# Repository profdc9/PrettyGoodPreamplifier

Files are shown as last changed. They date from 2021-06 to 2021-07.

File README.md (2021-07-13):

# Pretty Good Preamplifier

This is a stereo preamplifier circuit designed by Daniel Marks, including schematic and gerbers.

It has the following features:

1.  Four selectable audio sources, selected by relays.
2.  One of the audio sources is a balanced XLR input, the other three are unbalanced RCA inputs.
3.  Bass and treble tone control (Baxandall tone control).
4.  Balance control.
5.  A subwoofer output with adjustable gain and corner frequency between 20 and 100 Hz.
6.  Unbalanced and balanced (XLR) outputs for stereo and subwoofer channels.
7.  Supports a toggle power switch or a volume knob power switch.
8.  Can be turned on using remote trigger.
0.  Can send a remote trigger signal when turned on (for example to an amplifier).

It is a two-sided PCB that can be manufactured cheaply by, for example, JLCPCB or PCBWay.  The LM4562 is preferentially used for the op-amps, but NE5532 works fine too.  The XLR input uses a THAT1206 or INA137 integrated circuit.  The XLR output uses a THAT1646 or DRV134 integrated circuit.

Here is a picture of the PCB

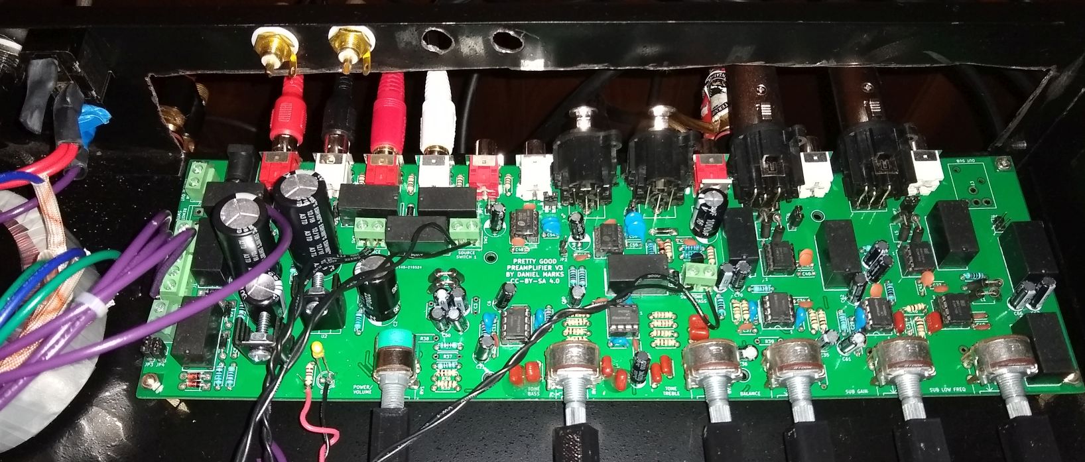
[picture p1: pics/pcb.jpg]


Here is a picture of the full preamplifier with the potentiometer extenders in the CAD directory:

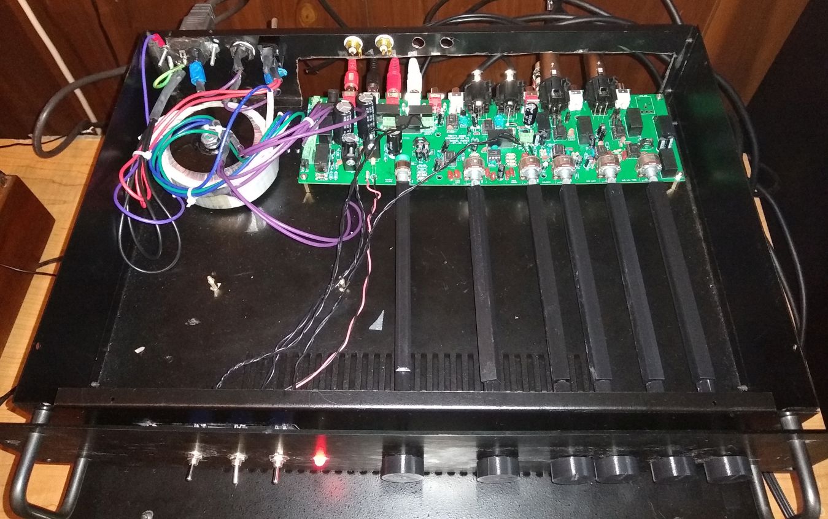
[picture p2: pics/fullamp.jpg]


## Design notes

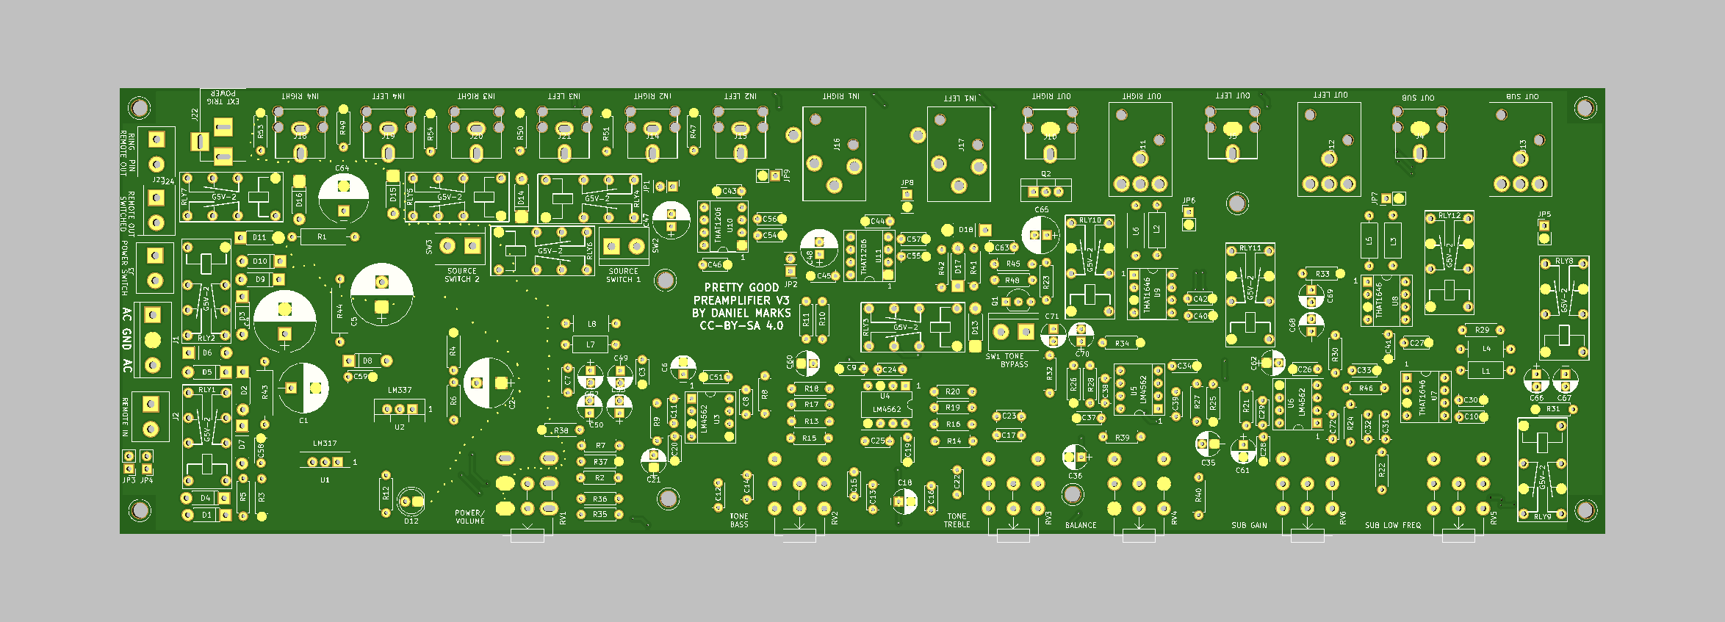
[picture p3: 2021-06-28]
Preamp.png

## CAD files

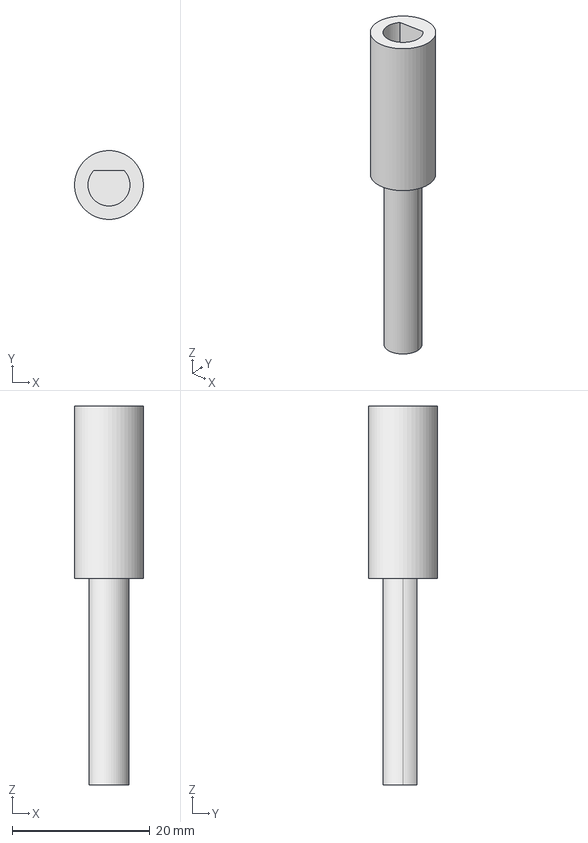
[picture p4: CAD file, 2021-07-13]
CAD/shaft-extender.FCStd
9.99 x 10.00 x 55.0 mm

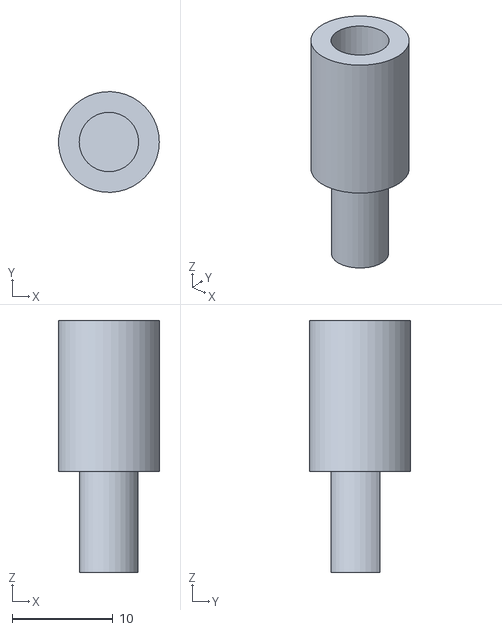
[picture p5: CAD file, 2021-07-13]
CAD/knobextender.stl
9.99 x 9.99 x 25.0

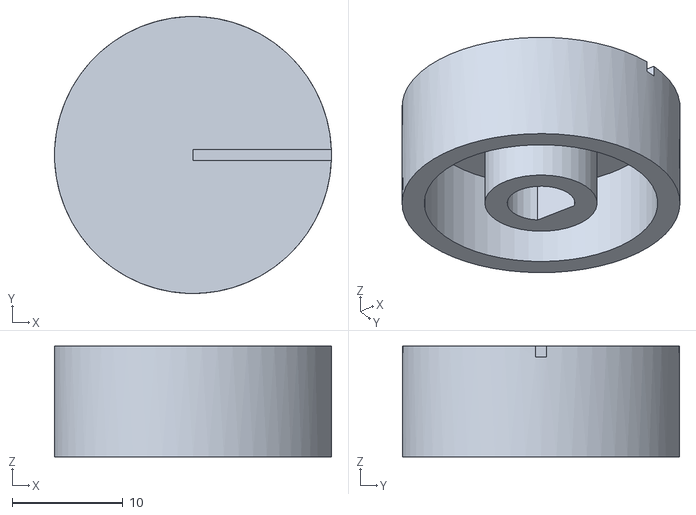
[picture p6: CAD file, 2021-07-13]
CAD/potentiometer-knob.stl
25.0 x 25.0 x 10.0

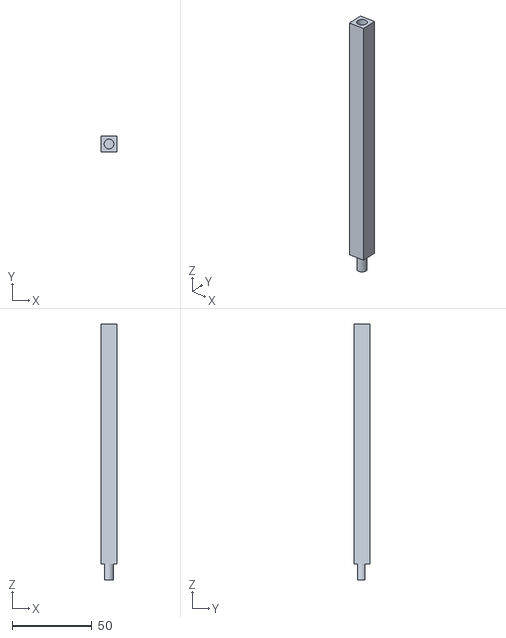
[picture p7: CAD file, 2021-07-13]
CAD/pot-extend-150mm.stl
10.0 x 10.0 x 160.0

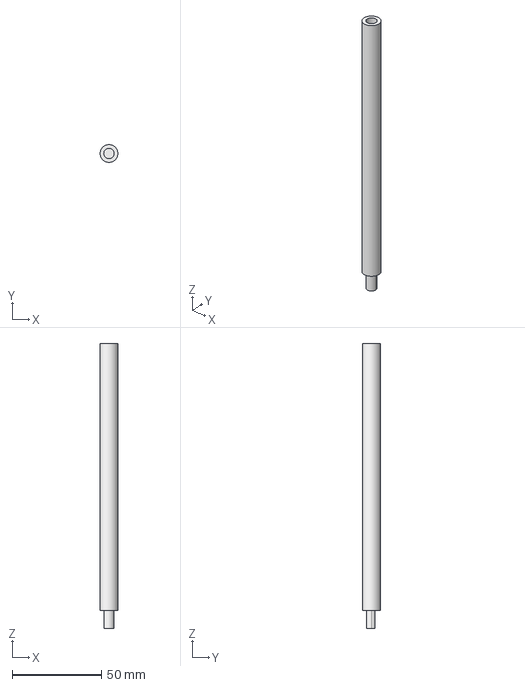
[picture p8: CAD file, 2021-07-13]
CAD/potentiometer-extender.FCStd
9.99 x 10.00 x 160.0 mm

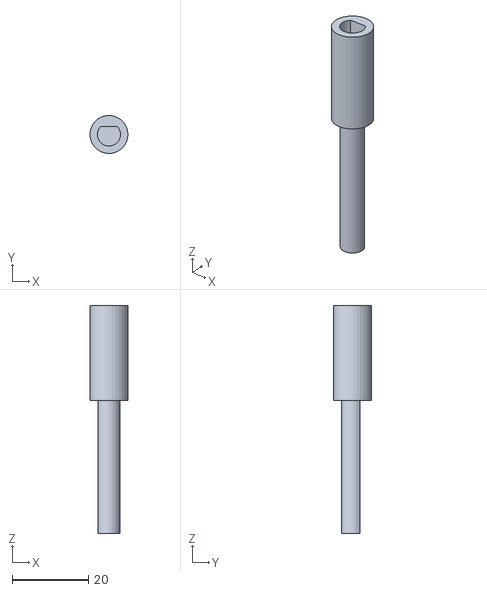
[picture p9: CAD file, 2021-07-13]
CAD/shaft-extender-35mm.stl
9.97 x 9.99 x 60.0

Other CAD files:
CAD/potentiometer-extender-square.FCStd
CAD/pot-extend-10mm-test.stl
CAD/custom-knob.FCStd
CAD/shaft-extender.stl

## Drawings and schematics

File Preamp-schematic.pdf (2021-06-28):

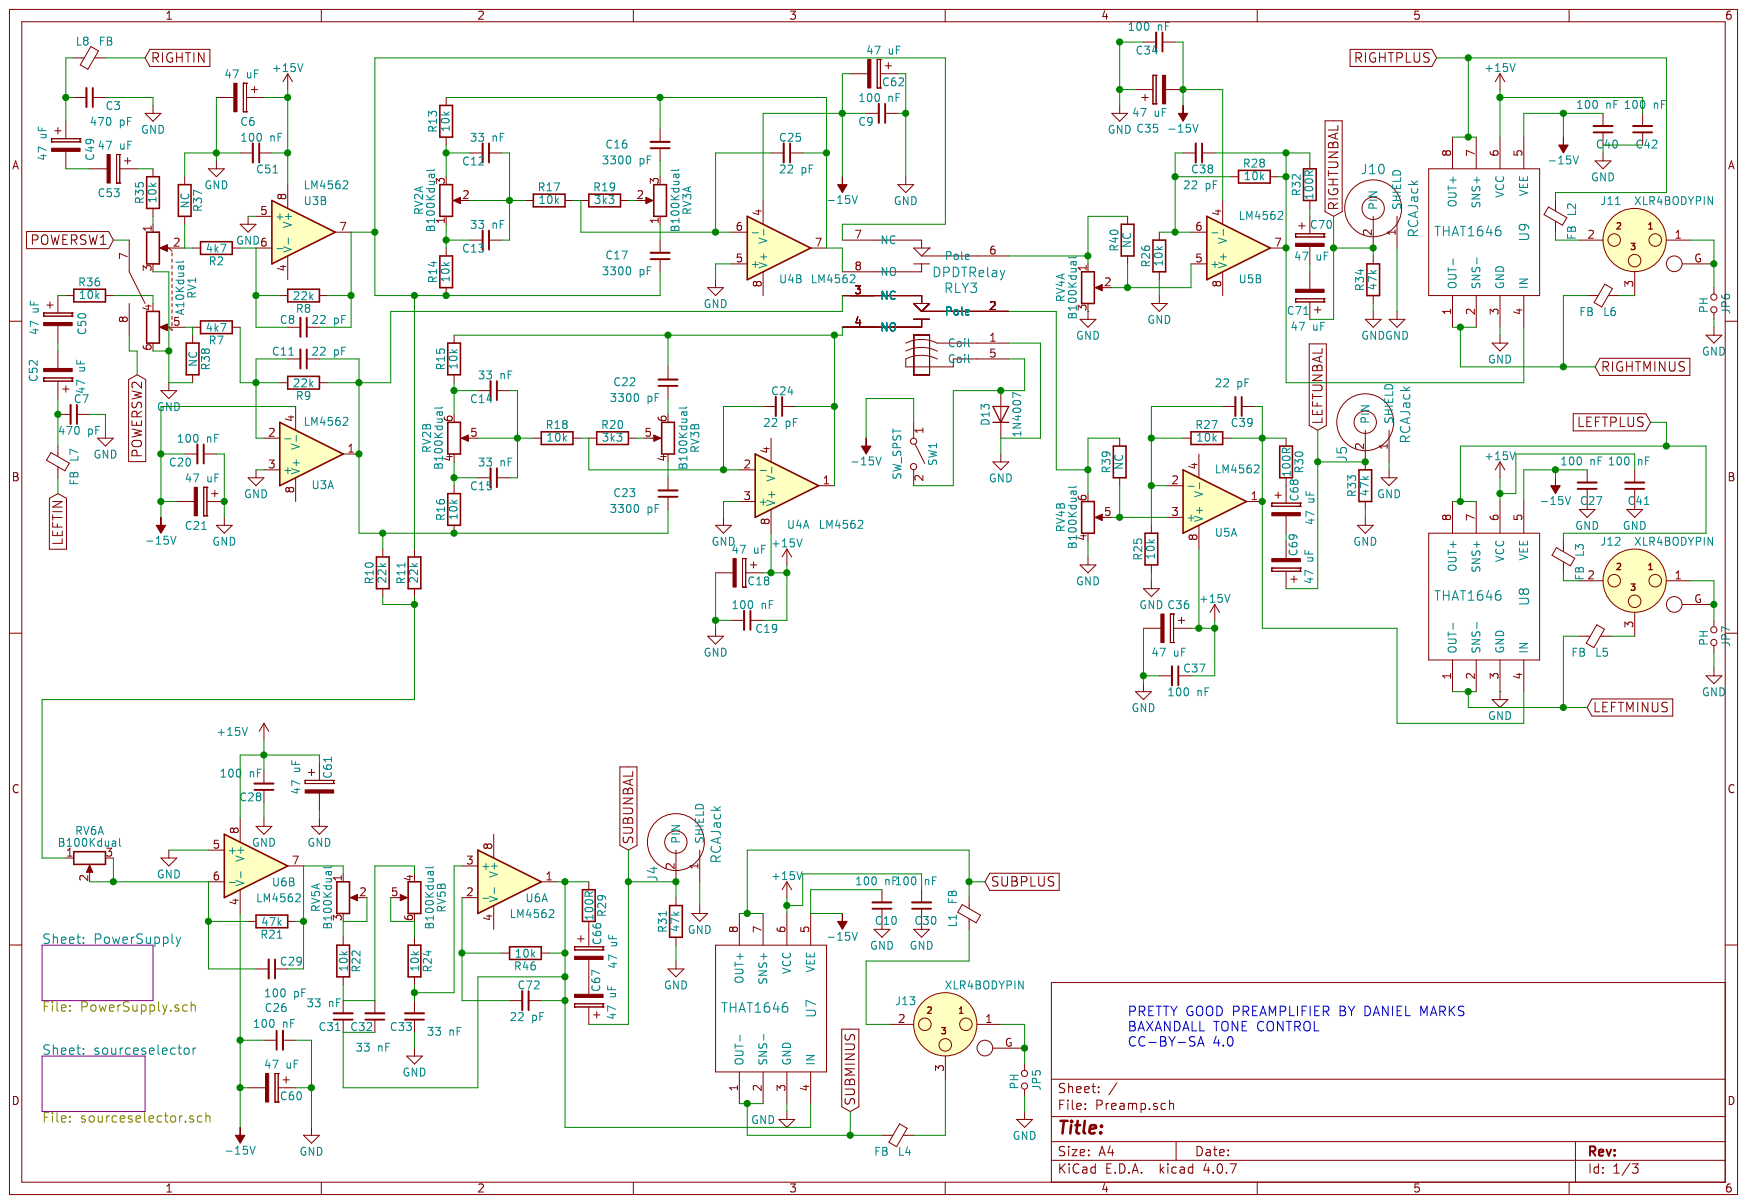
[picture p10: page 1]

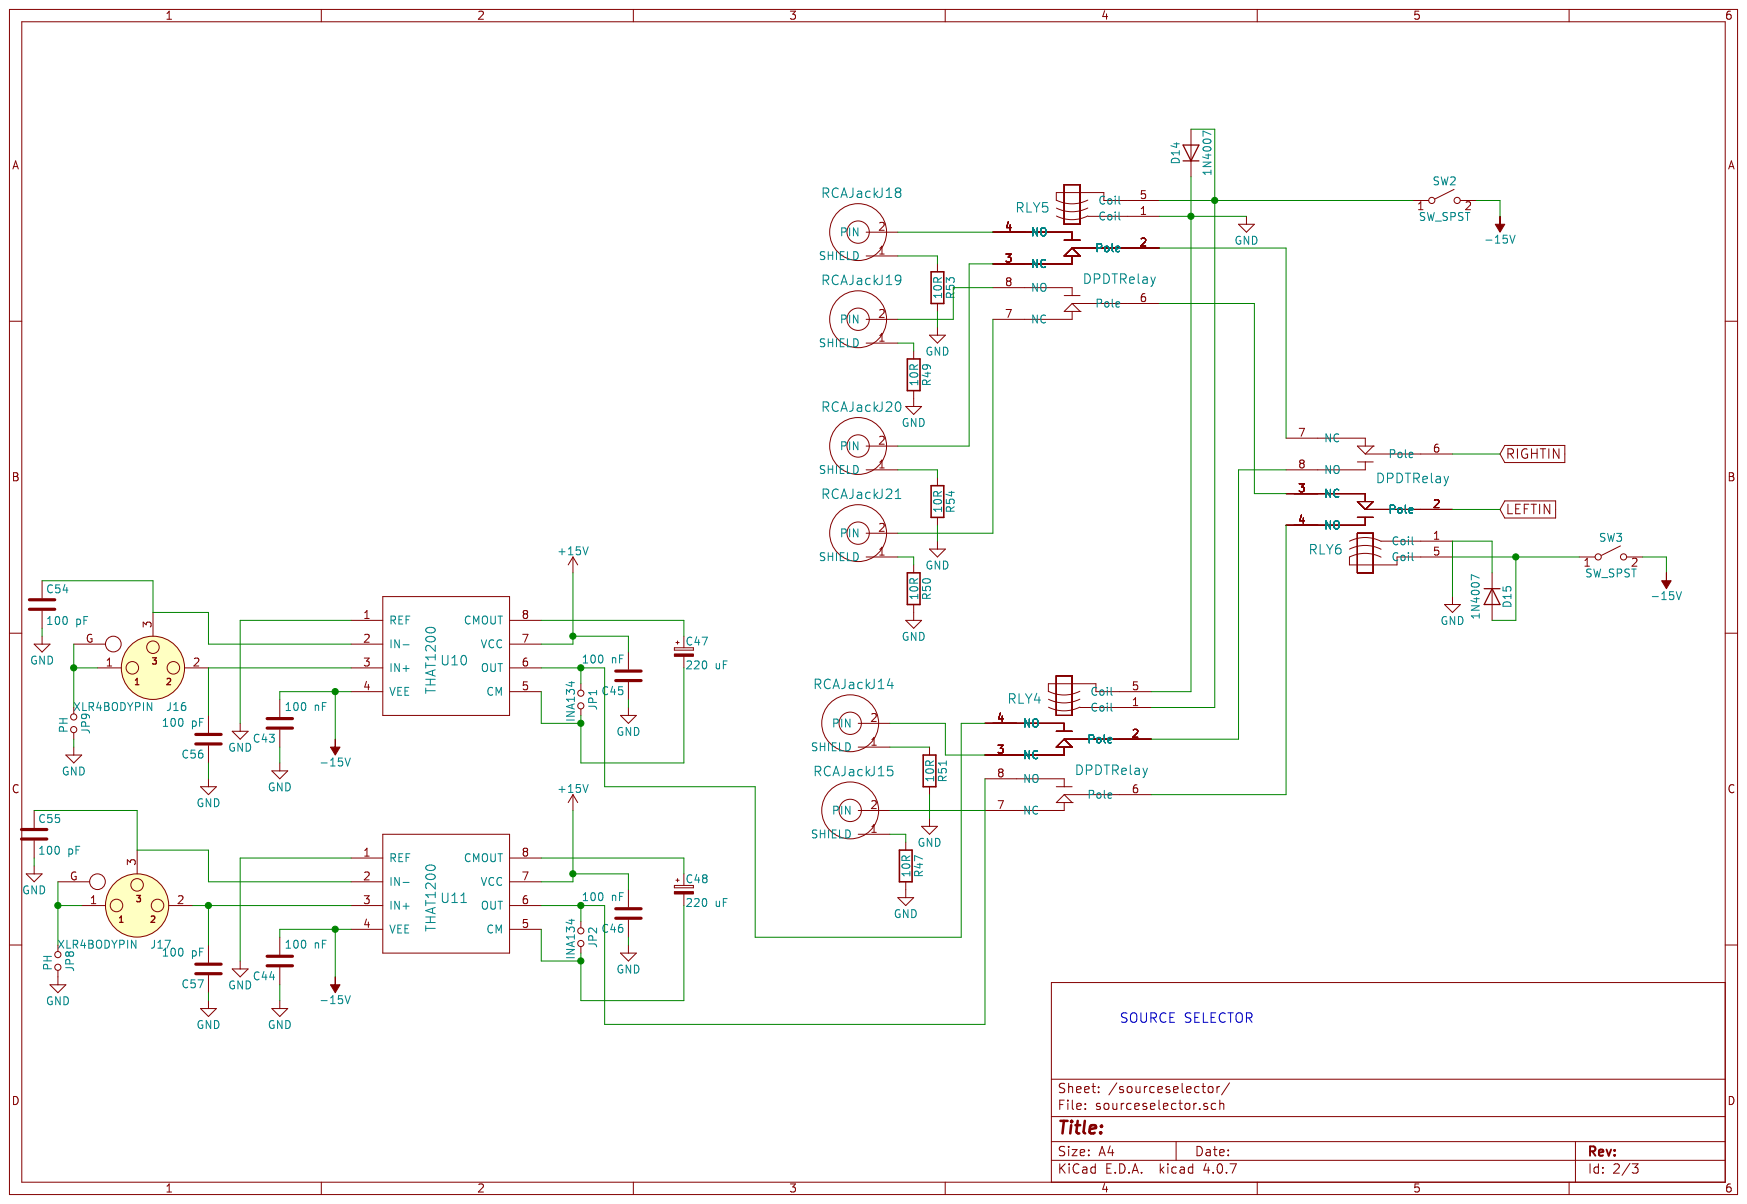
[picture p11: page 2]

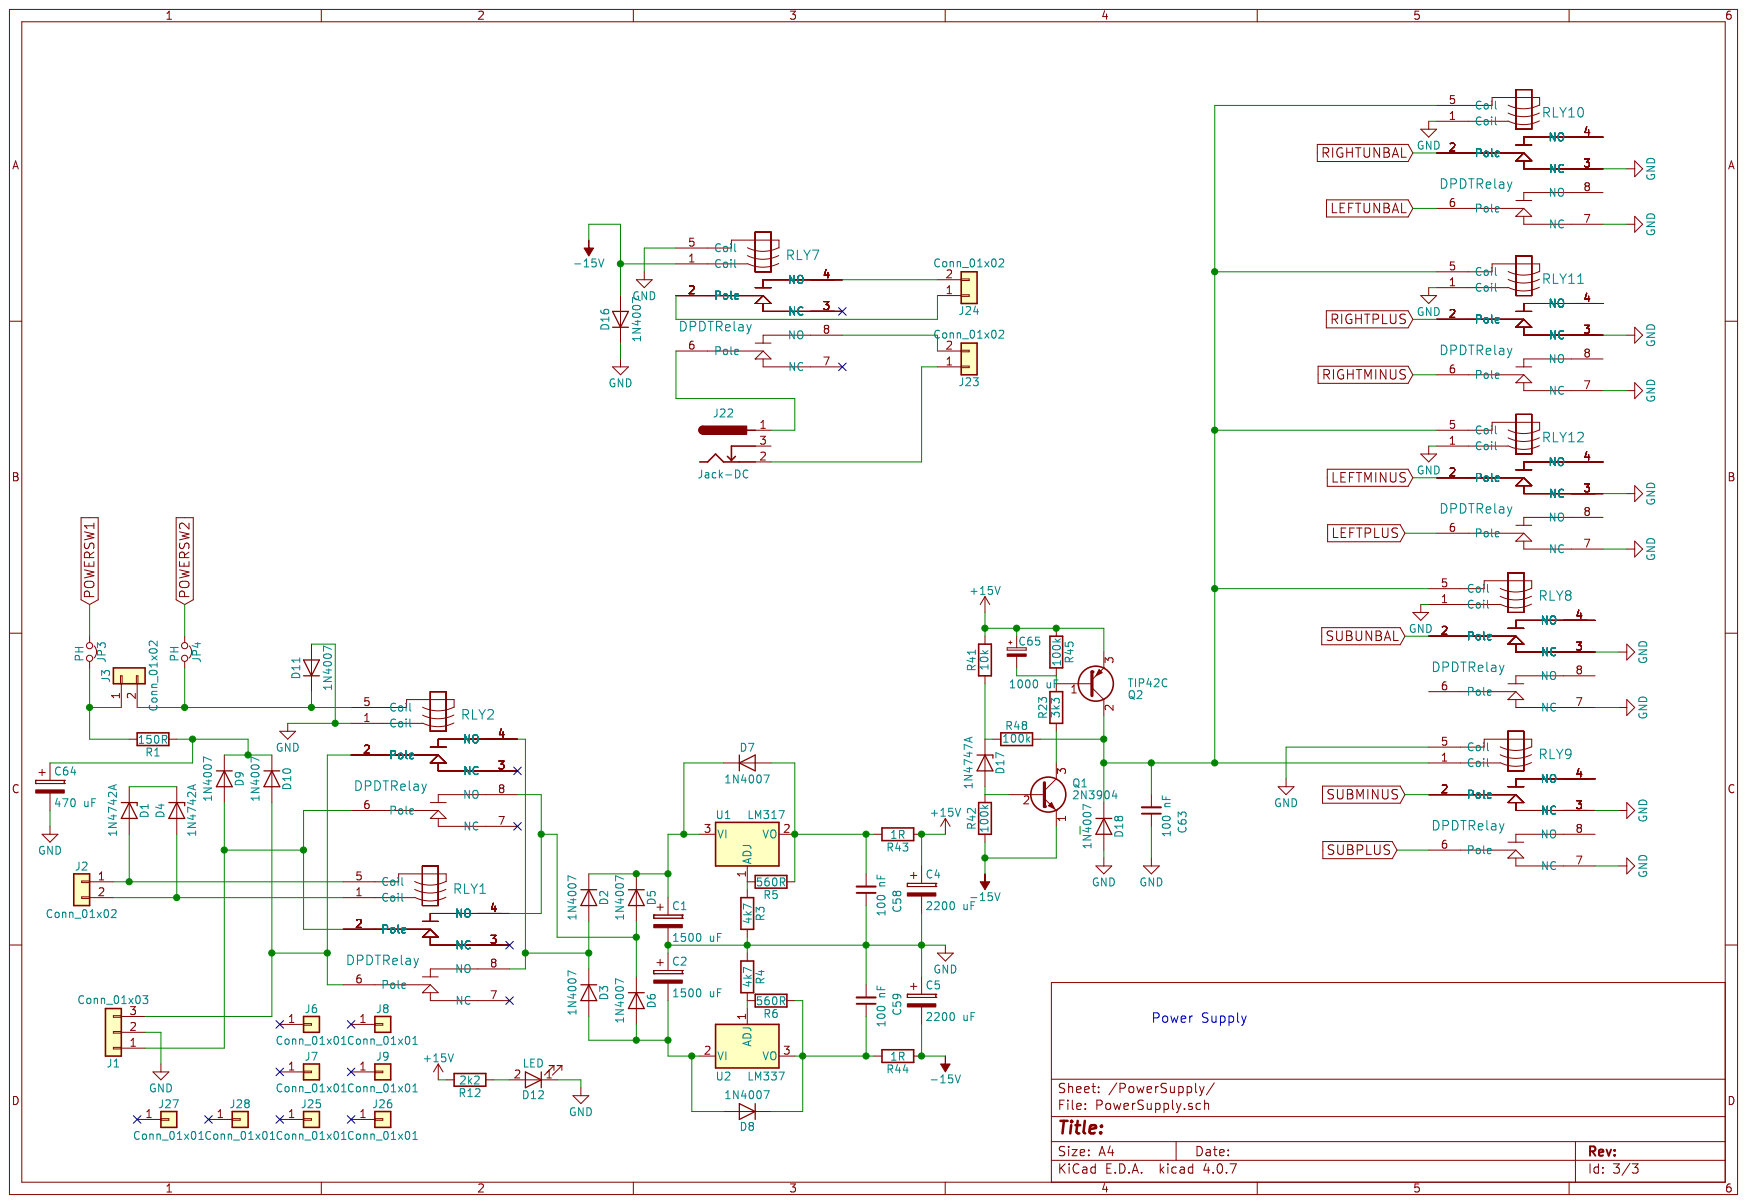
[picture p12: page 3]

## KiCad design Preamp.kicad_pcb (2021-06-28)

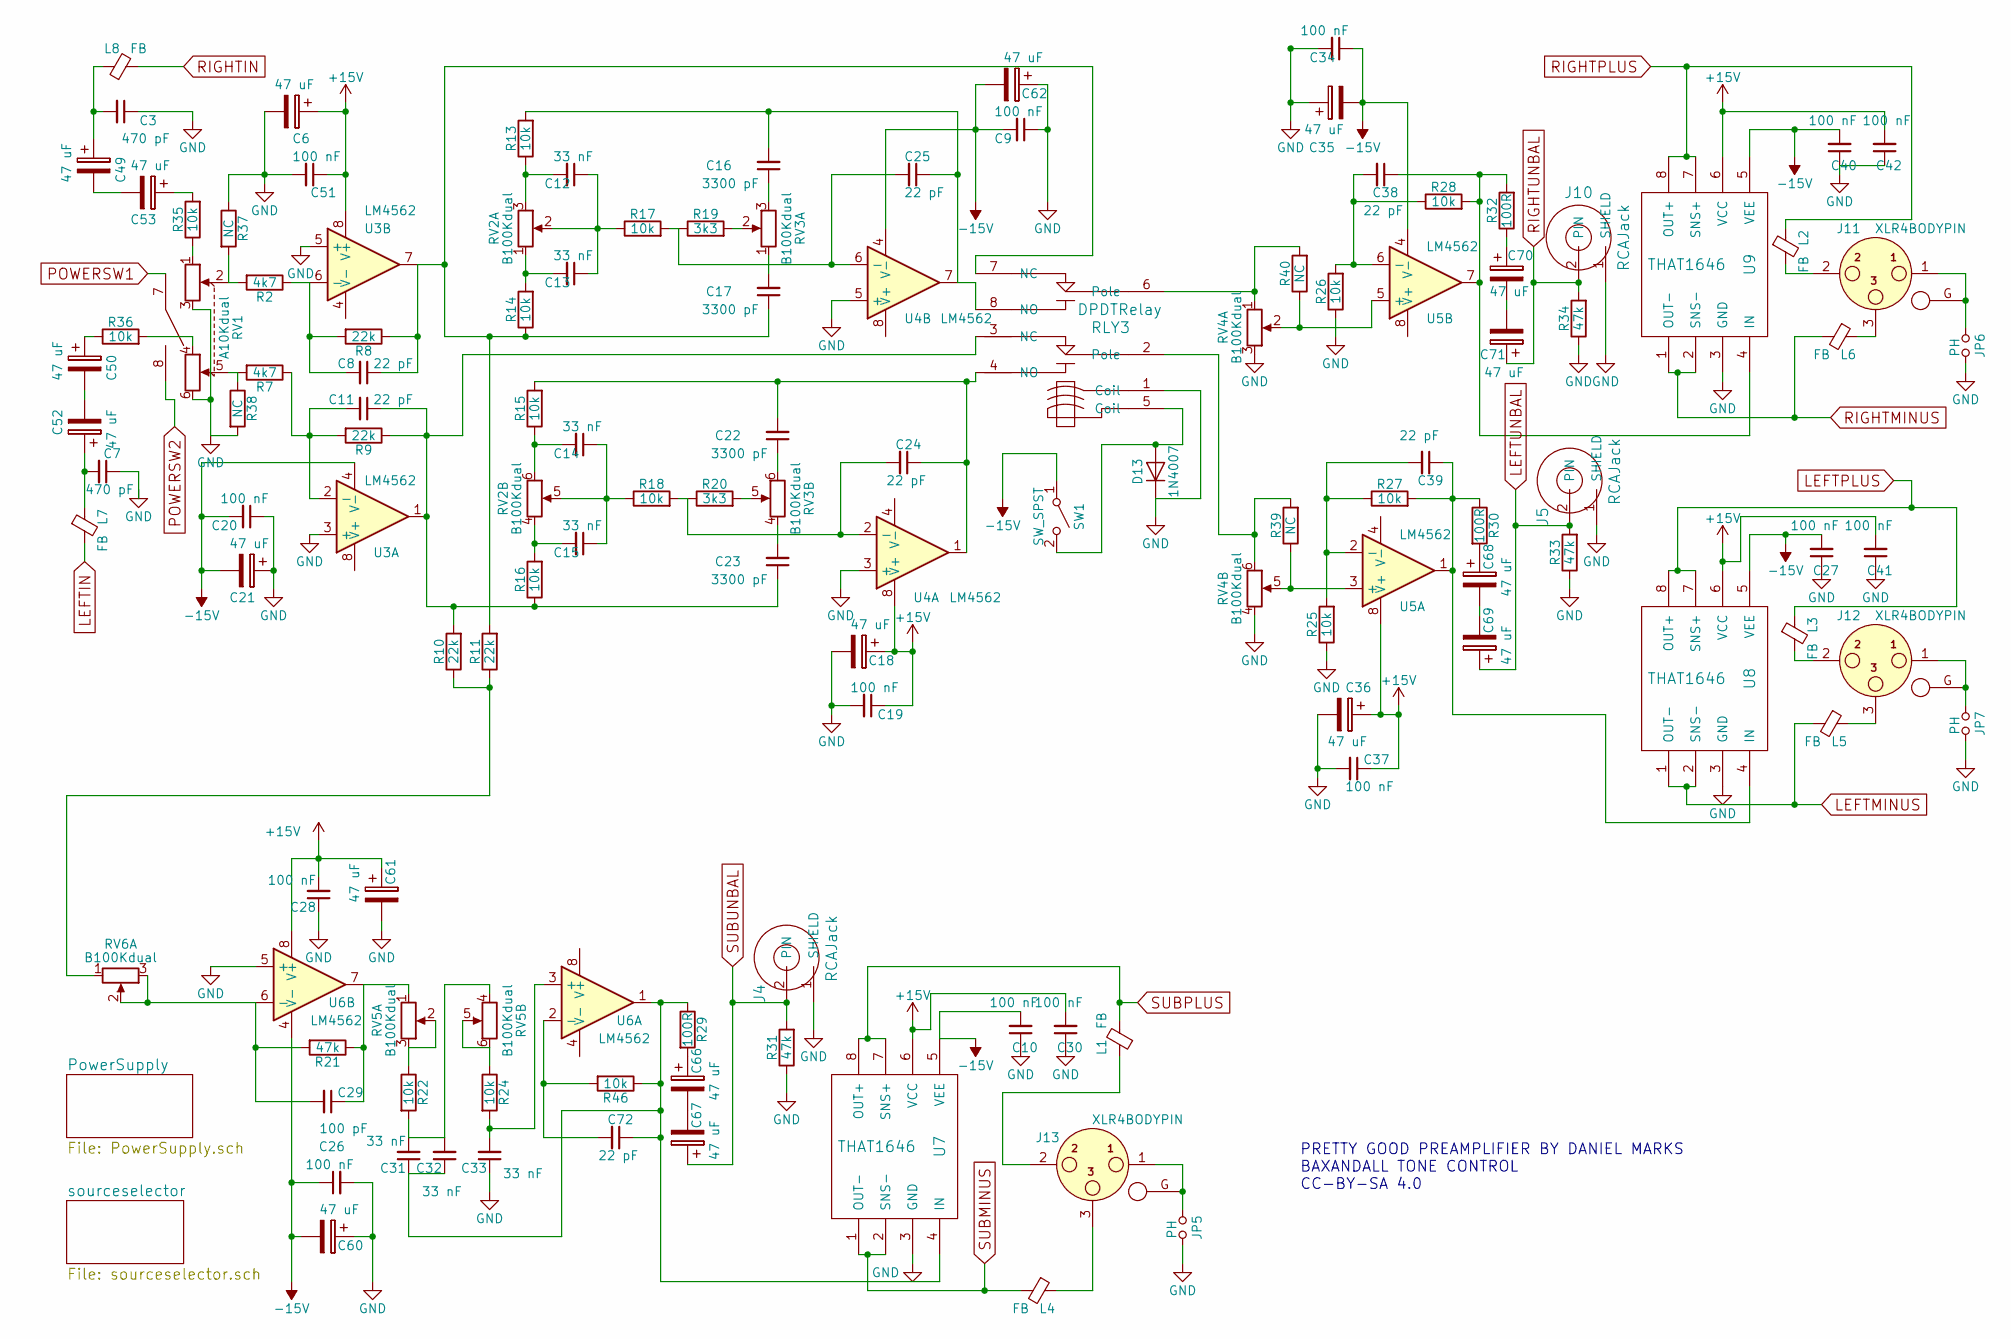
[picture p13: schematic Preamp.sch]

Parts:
C3, C7: 470 pF; C_Disc_D5.0mm_W2.5mm_P5.00mm
C6, C18, C21, C35, C36, C49, C50, C52, C53, C60, C61, C62, C66, C67, C68, C69, C70, C71: 47 uF; CP_Radial_D5.0mm_P2.50mm
C8, C11, C24, C25, C38, C39, C72: 22 pF; C_Disc_D5.0mm_W2.5mm_P5.00mm
C9, C10, C19, C20, C26, C27, C28, C30, C34, C37, C40, C41, C42, C51: 100 nF; C_Disc_D5.0mm_W2.5mm_P5.00mm
C12, C13, C14, C15, C31, C32, C33: 33 nF; C_Disc_D5.0mm_W2.5mm_P5.00mm
C16, C17, C22, C23: 3300 pF; C_Disc_D5.0mm_W2.5mm_P5.00mm
C29: 100 pF; C_Disc_D5.0mm_W2.5mm_P5.00mm
D13: 1N4007; D_DO-41_SOD81_P7.62mm_Horizontal
J4, J5, J10: RCAJack; RCAConnectorCommon
J11, J12, J13: XLR4BODYPIN; IOXLR3MEH
JP5, JP6, JP7: PH; Pin_Header_Straight_1x02_Pitch2.54mm
L1, L2, L3, L4, L5, L6, L7, L8: FB; L_Axial_L7.0mm_D3.3mm_P10.16mm_Horizontal_Fastron_MICC
R2, R7: 4k7; R_Axial_DIN0207_L6.3mm_D2.5mm_P7.62mm_Horizontal
R8, R9, R10, R11: 22k; R_Axial_DIN0207_L6.3mm_D2.5mm_P7.62mm_Horizontal
R13, R14, R15, R16, R17, R18, R22, R24, R25, R26, R27, R28, R35, R36, R46: 10k; R_Axial_DIN0207_L6.3mm_D2.5mm_P7.62mm_Horizontal
R19, R20: 3k3; R_Axial_DIN0207_L6.3mm_D2.5mm_P7.62mm_Horizontal
R21, R31, R33, R34: 47k; R_Axial_DIN0207_L6.3mm_D2.5mm_P7.62mm_Horizontal
R29, R30, R32: 100R; R_Axial_DIN0207_L6.3mm_D2.5mm_P7.62mm_Horizontal
R37, R38, R39, R40: NC; R_Axial_DIN0207_L6.3mm_D2.5mm_P7.62mm_Horizontal
RLY3: DPDTRelay; G2VRelay
RV1: A10Kdual; Dual_Potentiometer_Switch_Wide_WirePads
RV2, RV3, RV4, RV5, RV6: B100Kdual; Dual_Potentiometer_Switch_WirePads
SW1: SW_SPST; TerminalBlock_bornier-2_P5.08mm
U3, U4, U5, U6: LM4562; DIP-8_W7.62mm_Socket
U7, U8, U9: THAT1646; DIP-8_W7.62mm_Socket

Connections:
+15V: C6.1, C18.1, C19.1, C28.2, C30.2, C36.1, C37.1, C41.2, C42.2, C51.1, C61.1, U3.8 (V+), U4.8 (V+), U5.8 (V+), U6.8 (V+), U7.6 (VCC), U8.6 (VCC), U9.6 (VCC); also elsewhere on the board
-15V: C9.2, C10.2, C20.2, C21.2, C26.1, C27.2, C34.1, C35.2, C40.2, C60.2, C62.2, SW1.1 (A), U3.4 (V-), U4.4 (V-), U5.4 (V-), U6.4 (V-), U7.5 (VEE), U8.5 (VEE), U9.5 (VEE); also elsewhere on the board
LEFTIN: L7.2; also elsewhere on the board
LEFTMINUS: L5.2, U8.1 (OUT-), U8.2 (SNS-); also elsewhere on the board
LEFTPLUS: L3.1, U8.7 (SNS+), U8.8 (OUT+); also elsewhere on the board
LEFTUNBAL: C69.1, J5.2 (PIN), R33.2; also elsewhere on the board
unnamed: C3.2, C49.1, L8.1
unnamed: C8.2, R2.1, R8.2, U3.6 (-)
unnamed: C11.1, C23.1, R9.1, R10.2, R16.1, RLY3.3 (NC), U3.1
unnamed: C11.2, R7.1, R9.2, U3.2 (-)
unnamed: C12.1, C13.1, R17.1, RV2.2 (5)
unnamed: C12.2, R13.1, RV2.3 (6)
unnamed: C13.2, R14.2, RV2.1 (4)
unnamed: C14.1, C15.1, R18.1, RV2.5
unnamed: C14.2, R15.1, RV2.6
unnamed: C15.2, R16.2, RV2.4
unnamed: C16.1, RV3.3 (6)
unnamed: C16.2, C25.1, R13.2, RLY3.8 (NO), U4.7
unnamed: C8.1, C17.1, R8.1, R11.2, R14.1, RLY3.7 (NC), U3.7
unnamed: C17.2, RV3.1 (4)
unnamed: C22.1, RV3.6
unnamed: C22.2, C24.1, R15.2, RLY3.4 (NO), U4.1
unnamed: C23.2, RV3.4
unnamed: C24.2, R18.2, R20.1, U4.2 (-)
unnamed: C25.2, R17.2, R19.1, U4.6 (-)
unnamed: C29.1, R21.1, RV5.1 (4), U6.7
unnamed: C29.2, R21.2, RV6.2 (5), RV6.3 (6), U6.6 (-)
unnamed: C31.1, C32.1, C72.1, R29.1, R46.1, U6.1, U7.4 (IN)
unnamed: C31.2, C32.2, R22.2, RV5.4
unnamed: C33.2, R24.2, U6.3 (+)
unnamed: C38.1, R28.2, R32.2, U5.7, U9.4 (IN)
unnamed: C38.2, R26.2, R28.1, U5.6 (-)
unnamed: C39.1, R27.2, R30.1, U5.1, U8.4 (IN)
unnamed: C39.2, R25.2, R27.1, U5.2 (-)
unnamed: C49.2, C53.2
unnamed: C50.1, R36.1
unnamed: C50.2, C52.2
unnamed: C7.2, C52.1, L7.1
unnamed: C53.1, R35.2
unnamed: C66.1, R29.2
unnamed: C66.2, C67.2
unnamed: C68.1, R30.2
unnamed: C68.2, C69.2
unnamed: C70.1, R32.1
unnamed: C70.2, C71.2
unnamed: C72.2, R46.2, U6.2 (-)
unnamed: D13.2 (A), RLY3.5 (Coil), SW1.2 (B)
unnamed: J11.1, J11.G, JP6.1
unnamed: J11.2, L2.2
unnamed: J11.3, L6.1
unnamed: J12.1, J12.G, JP7.1
unnamed: J12.2, L3.2
unnamed: J12.3, L5.1
unnamed: J13.1, J13.G, JP5.1
unnamed: J13.2, L1.1
unnamed: J13.3, L4.1
unnamed: R2.2, R37.2, RV1.2
unnamed: R10.1, R11.1, RV6.1 (4)
unnamed: R19.2, RV3.2 (5)
unnamed: R20.2, RV3.5
unnamed: R22.1, RV5.2 (5), RV5.3 (6)
unnamed: R24.1, RV5.5, RV5.6
unnamed: R35.1, RV1.1
unnamed: R36.2, RV1.4
unnamed: R7.2, R38.1, RV1.5
unnamed: R39.1, RV4.5, U5.3 (+)
unnamed: R39.2, RLY3.2 (Pole), RV4.6
unnamed: R40.1, RV4.2 (5), U5.5 (+)
unnamed: R40.2, RLY3.6 (Pole), RV4.1 (4)
POWERSW1: RV1.7 (SW1); also elsewhere on the board
POWERSW2: RV1.8; also elsewhere on the board
RIGHTIN: L8.2; also elsewhere on the board
RIGHTMINUS: L6.2, U9.1 (OUT-), U9.2 (SNS-); also elsewhere on the board
RIGHTPLUS: L2.1, U9.7 (SNS+), U9.8 (OUT+); also elsewhere on the board
RIGHTUNBAL: C71.1, J10.2 (PIN), R34.2; also elsewhere on the board
SUBMINUS: L4.2, U7.1 (OUT-), U7.2 (SNS-); also elsewhere on the board
SUBPLUS: L1.2, U7.7 (SNS+), U7.8 (OUT+); also elsewhere on the board
SUBUNBAL: C67.1, J4.2 (PIN), R31.2; also elsewhere on the board

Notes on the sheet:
PRETTY GOOD PREAMPLIFIER BY DANIEL MARKS BAXANDALL TONE CONTROL CC-BY-SA 4.0

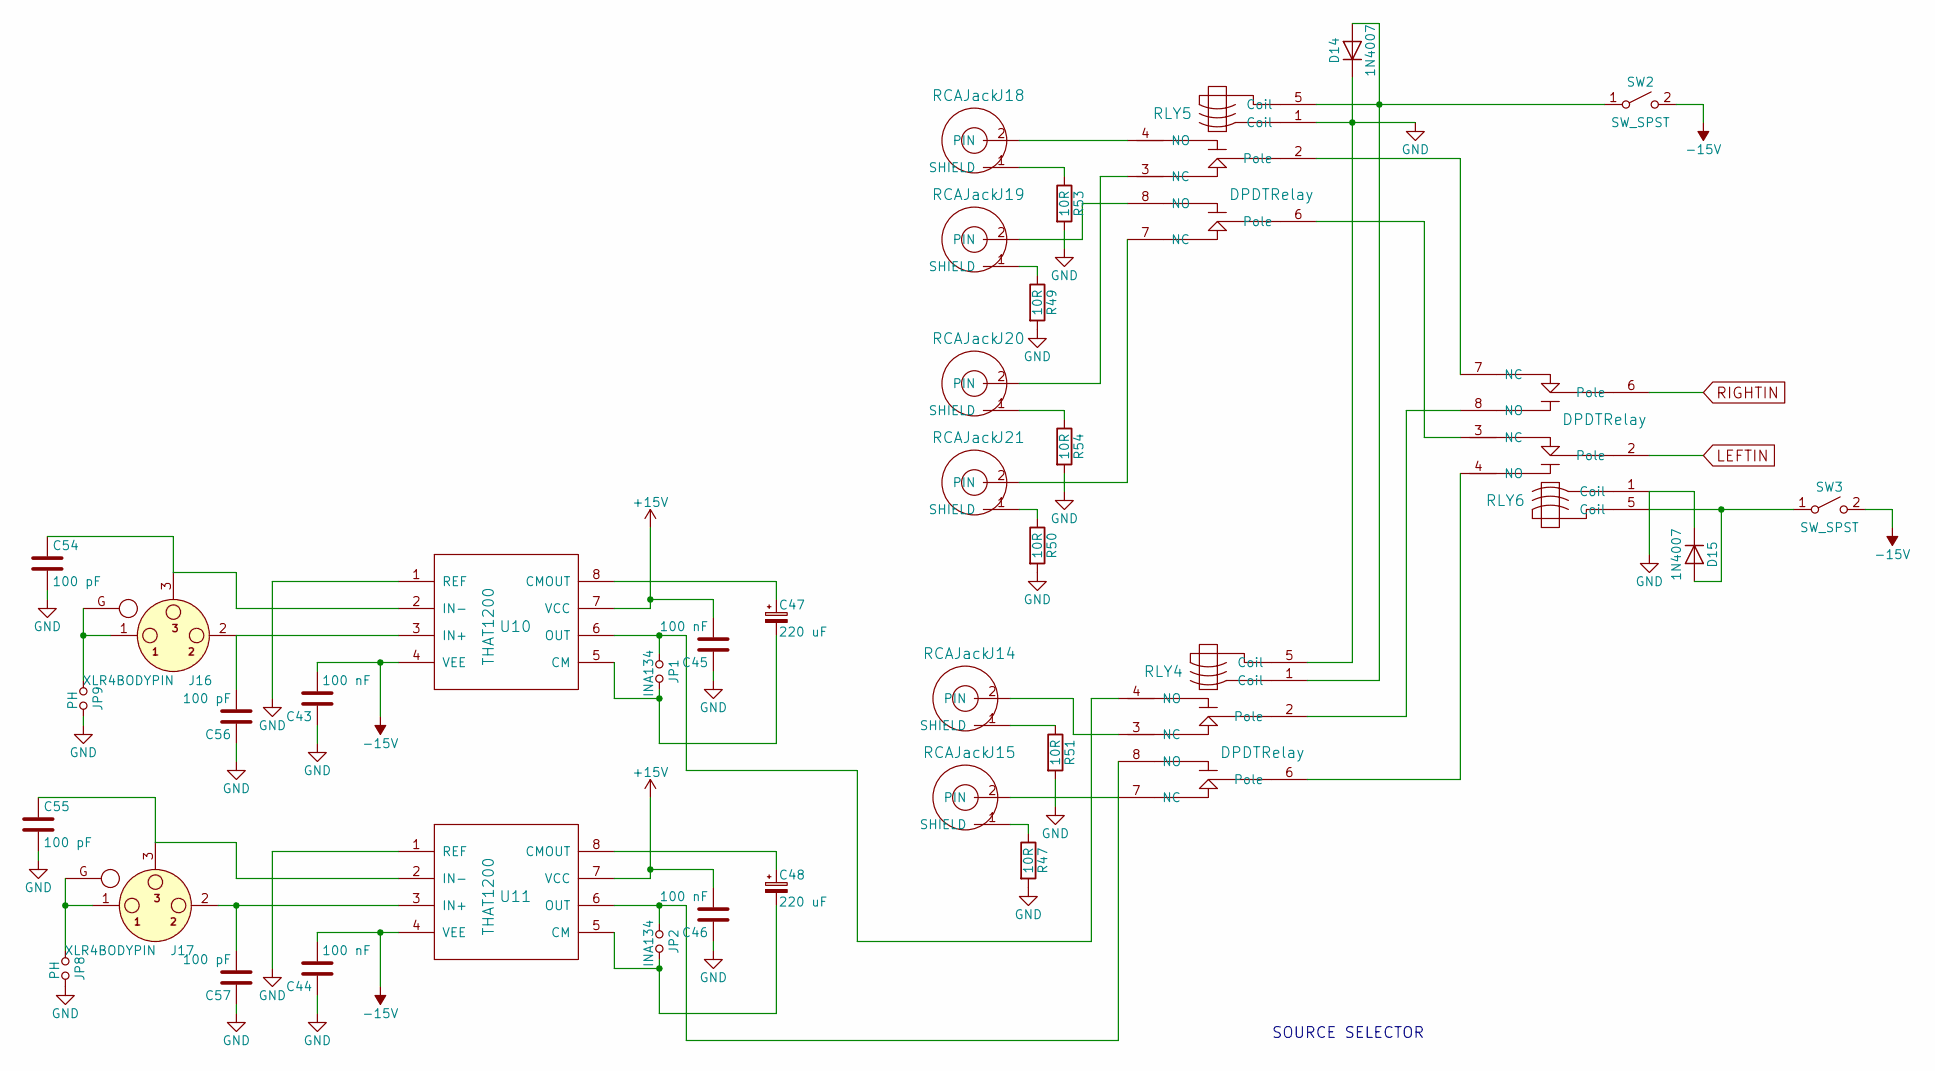
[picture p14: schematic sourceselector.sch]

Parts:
C43, C44, C45, C46: 100 nF; C_Disc_D5.0mm_W2.5mm_P5.00mm
C47, C48: 220 uF; CP_Radial_D7.5mm_P2.50mm
C54, C55, C56, C57: 100 pF; C_Disc_D5.0mm_W2.5mm_P5.00mm
D14, D15: 1N4007; D_DO-41_SOD81_P7.62mm_Horizontal
J14, J15, J18, J19, J20, J21: RCAJack; RCAConnectorCommon
J16, J17: XLR4BODYPIN; IOXLR3FEH
JP1, JP2: INA134; Pin_Header_Straight_1x02_Pitch2.54mm
JP8, JP9: PH; Pin_Header_Straight_1x02_Pitch2.54mm
R47, R49, R50, R51, R53, R54: 10R; R_Axial_DIN0207_L6.3mm_D2.5mm_P7.62mm_Horizontal
RLY4, RLY5, RLY6: DPDTRelay; G2VRelay
SW2, SW3: SW_SPST; TerminalBlock_bornier-2_P5.08mm
U10, U11: THAT1200; DIP-8_W7.62mm_Socket

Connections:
+15V: C45.2, C46.2, U10.7 (VCC), U11.7 (VCC); also elsewhere on the board
-15V: C43.2, C44.2, SW2.2 (B), SW3.2 (B), U10.4 (VEE), U11.4 (VEE); also elsewhere on the board
LEFTIN: RLY6.2 (Pole); also elsewhere on the board
unnamed: C47.1, U10.8 (CMOUT)
unnamed: C47.2, JP1.2, U10.5 (CM)
unnamed: C48.1, U11.8 (CMOUT)
unnamed: C48.2, JP2.2, U11.5 (CM)
unnamed: C54.1, J16.3, U10.2 (IN-)
unnamed: C55.1, J17.3, U11.2 (IN-)
unnamed: C56.2, J16.2, U10.3 (IN+)
unnamed: C57.2, J17.2, U11.3 (IN+)
unnamed: D14.2 (A), RLY4.1 (Coil), RLY5.5 (Coil), SW2.1 (A)
unnamed: D15.2 (A), RLY6.5 (Coil), SW3.1 (A)
unnamed: J14.1 (SHIELD), R51.1
unnamed: J14.2 (PIN), RLY4.3 (NC)
unnamed: J15.1 (SHIELD), R47.1
unnamed: J15.2 (PIN), RLY4.7 (NC)
unnamed: J16.1, J16.G, JP9.1
unnamed: J17.1, J17.G, JP8.1
unnamed: J18.1 (SHIELD), R53.1
unnamed: J18.2 (PIN), RLY5.4 (NO)
unnamed: J19.1 (SHIELD), R49.1
unnamed: J19.2 (PIN), RLY5.8 (NO)
unnamed: J20.1 (SHIELD), R54.1
unnamed: J20.2 (PIN), RLY5.3 (NC)
unnamed: J21.1 (SHIELD), R50.1
unnamed: J21.2 (PIN), RLY5.7 (NC)
unnamed: JP1.1, RLY4.4 (NO), U10.6 (OUT)
unnamed: JP2.1, RLY4.8 (NO), U11.6 (OUT)
unnamed: RLY4.2 (Pole), RLY6.8 (NO)
unnamed: RLY4.6 (Pole), RLY6.4 (NO)
unnamed: RLY5.2 (Pole), RLY6.7 (NC)
unnamed: RLY5.6 (Pole), RLY6.3 (NC)
RIGHTIN: RLY6.6 (Pole); also elsewhere on the board

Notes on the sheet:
SOURCE SELECTOR

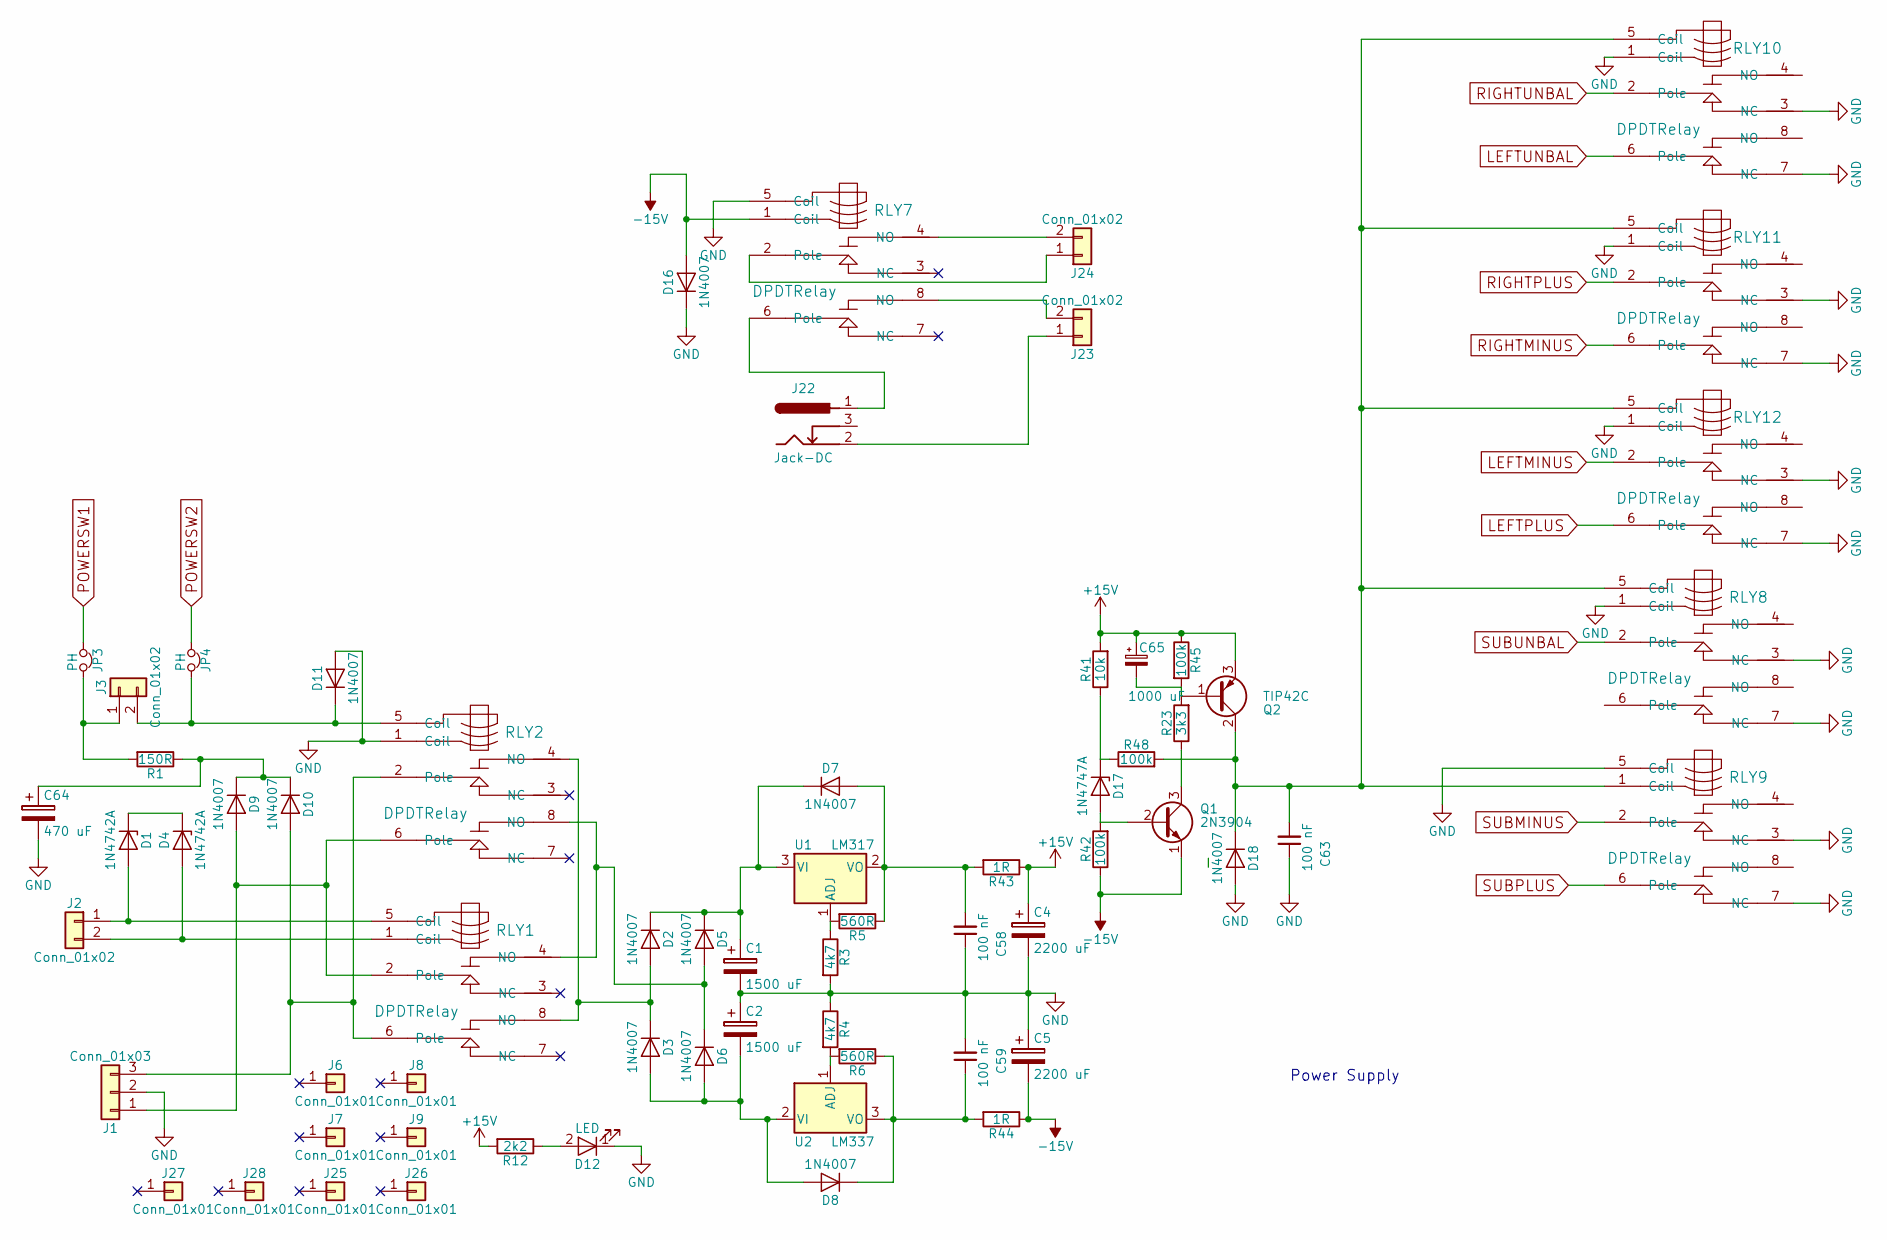
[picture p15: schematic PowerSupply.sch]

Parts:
C1, C2: 1500 uF; CP_Radial_D10.0mm_P5.00mm
C4, C5: 2200 uF; CP_Radial_D12.5mm_P5.00mm
C58, C59, C63: 100 nF; C_Disc_D5.0mm_W2.5mm_P5.00mm
C64: 470 uF; CP_Radial_D10.0mm_P5.00mm
C65: 1000 uF; CP_Radial_D7.5mm_P2.50mm
D1, D4: 1N4742A; D_DO-41_SOD81_P7.62mm_Horizontal
D2, D3, D5, D6, D7, D8, D9, D10, D11, D16, D18: 1N4007; D_DO-41_SOD81_P7.62mm_Horizontal
D12: LED; LED_D5.0mm
D17: 1N4747A; D_DO-41_SOD81_P7.62mm_Horizontal
J1: Conn_01x03; TerminalBlock_bornier-3_P5.08mm
J2, J3, J23, J24: Conn_01x02; TerminalBlock_bornier-2_P5.08mm
J6, J7, J8, J9, J25, J26, J27, J28: Conn_01x01; 1pin
J22: Jack-DC; BARREL_JACK
JP3, JP4: PH; Pin_Header_Straight_1x02_Pitch2.54mm
Q1: 2N3904; TO-92_Inline_Wide
Q2: TIP42C; TO-220-3_Vertical
R1: 150R; R_Axial_DIN0309_L9.0mm_D3.2mm_P12.70mm_Horizontal
R3, R4: 4k7; R_Axial_DIN0207_L6.3mm_D2.5mm_P7.62mm_Horizontal
R5, R6: 560R; R_Axial_DIN0207_L6.3mm_D2.5mm_P7.62mm_Horizontal
R12: 2k2; R_Axial_DIN0207_L6.3mm_D2.5mm_P7.62mm_Horizontal
R23: 3k3; R_Axial_DIN0207_L6.3mm_D2.5mm_P7.62mm_Horizontal
R41: 10k; R_Axial_DIN0207_L6.3mm_D2.5mm_P7.62mm_Horizontal
R42, R45, R48: 100k; R_Axial_DIN0207_L6.3mm_D2.5mm_P7.62mm_Horizontal
R43, R44: 1R; R_Axial_DIN0309_L9.0mm_D3.2mm_P12.70mm_Horizontal
RLY1, RLY2, RLY7, RLY8, RLY9, RLY10, RLY11, RLY12: DPDTRelay; G2VRelay
U1: LM317; TO-220-3_Vertical
U2: LM337; TO-220-3_Vertical

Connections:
+15V: C4.1, C65.1, Q2.3 (E), R12.2, R41.2, R43.1, R45.1; also elsewhere on the board
-15V: C5.2, D16.2 (A), Q1.1 (E), R42.1, R44.1, RLY7.1 (Coil); also elsewhere on the board
LEFTMINUS: RLY12.2 (Pole); also elsewhere on the board
LEFTPLUS: RLY12.6 (Pole); also elsewhere on the board
LEFTUNBAL: RLY10.6 (Pole); also elsewhere on the board
unnamed: C1.1, D2.1 (K), D5.1 (K), D7.1 (K), U1.3 (VI)
unnamed: C2.2, D3.2 (A), D6.2 (A), D8.2 (A), U2.2 (VI)
unnamed: C58.2, D7.2 (A), R5.1, R43.2, U1.2 (VO)
unnamed: C59.1, D8.1 (K), R6.1, R44.2, U2.3 (VO)
unnamed: C63.2, D18.1 (K), Q2.2 (C), R48.2, RLY8.5 (Coil), RLY9.1 (Coil), RLY10.5 (Coil), RLY11.5 (Coil), RLY12.5 (Coil)
unnamed: C64.1, D9.1 (K), D10.1 (K), R1.1
unnamed: C65.2, Q2.1 (B), R23.2, R45.2
unnamed: D1.1 (K), D4.1 (K)
unnamed: D1.2 (A), J2.1, RLY1.5 (Coil)
unnamed: D2.2 (A), D3.1 (K), RLY1.8 (NO), RLY2.4 (NO)
unnamed: D4.2 (A), J2.2, RLY1.1 (Coil)
unnamed: D5.2 (A), D6.1 (K), RLY1.4 (NO), RLY2.8 (NO)
unnamed: D9.2 (A), J1.1, RLY1.2 (Pole), RLY2.6 (Pole)
unnamed: D10.2 (A), J1.3, RLY1.6 (Pole), RLY2.2 (Pole)
unnamed: D11.1 (K), J3.2, JP4.2, RLY2.5 (Coil)
unnamed: D12.2 (A), R12.1
unnamed: D17.1 (K), R41.1, R48.1
unnamed: D17.2 (A), Q1.2 (B), R42.2
unnamed: J3.1, JP3.2, R1.2
unnamed: J22.1, RLY7.6 (Pole)
unnamed: J22.2, J23.1
unnamed: J23.2, RLY7.8 (NO)
unnamed: J24.1, RLY7.2 (Pole)
unnamed: J24.2, RLY7.4 (NO)
unnamed: Q1.3 (C), R23.1
unnamed: R3.1, R5.2, U1.1 (ADJ)
unnamed: R4.2, R6.2, U2.1 (ADJ)
POWERSW1: JP3.1; also elsewhere on the board
POWERSW2: JP4.1; also elsewhere on the board
RIGHTMINUS: RLY11.6 (Pole); also elsewhere on the board
RIGHTPLUS: RLY11.2 (Pole); also elsewhere on the board
RIGHTUNBAL: RLY10.2 (Pole); also elsewhere on the board
SUBMINUS: RLY9.2 (Pole); also elsewhere on the board
SUBPLUS: RLY9.6 (Pole); also elsewhere on the board
SUBUNBAL: RLY8.2 (Pole); also elsewhere on the board

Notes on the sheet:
Power Supply

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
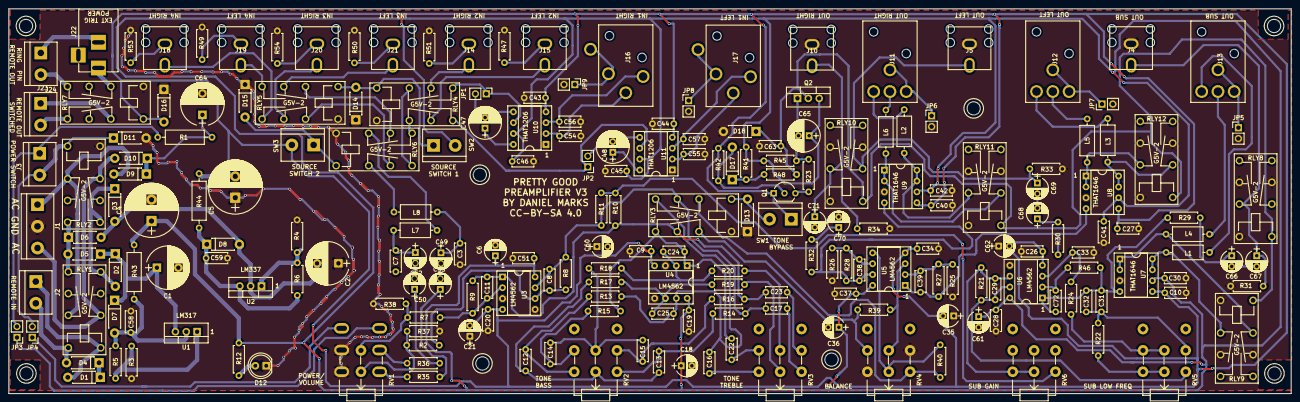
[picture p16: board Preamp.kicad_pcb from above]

Board: 2 copper layers, 300.0 x 90.0 mm, 222 parts (0 on the bottom side), 136 nets.

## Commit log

2021-03-18 Changed balanced output to THAT1646
    [Preamp-B.Cu.gbr, Preamp-B.Mask.gbr, Preamp-B.SilkS.gbr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]
2021-03-18 Changed one input to be balanced
    [Baxandall-Tone-Control.sch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]
2021-03-19 Before changing RCA jacks
    [Preamp-B.Cu.gbr, Preamp-B.Mask.gbr, Preamp-B.SilkS.gbr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]
2021-03-26 JLCPCB 2021-03-26
    [Preamp-B.Cu.gbr, Preamp-B.Mask.gbr, Preamp-B.SilkS.gbr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]
2021-04-02 Pre off relay
    [Baxandall-Tone-Control-Noise.sch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]
2021-04-02 Tried a relay version out
    [Preamp-B.Cu.gbr, Preamp-B.Mask.gbr, Preamp-B.SilkS.gbr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]
2021-04-02 Put larger capacitors on
    [Preamp-B.Cu.gbr, Preamp-B.Mask.gbr, Preamp-B.SilkS.gbr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]
2021-04-06 remove screwy UVLO
    [Preamp-B.Cu.gbr, Preamp-B.Mask.gbr, Preamp-B.SilkS.gbr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]
2021-04-07 Now grounds all of the outputs when supply is below 20 V
    [PowerSupply.sch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]
2021-04-13 JLCPCB order 2021-04-11
    [PowerSupply.sch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]
2021-04-29 Moved around a component to make a little more space
    [PowerSupply.sch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]
2021-05-04 Added jumpers to connect shields of XLR to ground
    [Baxandall-Tone-Control.sch, PowerSupply.sch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]
2021-05-28 JLCPCB manufacturing
    [PowerSupply.sch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]
2021-06-28 A few minor changes to fix crowding of components
    [PowerSupply.sch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]
2021-07-13 Added some more CAD files
    [knobextender.stl, pot-extend-10mm-test.stl, pot-extend-150mm.stl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]
